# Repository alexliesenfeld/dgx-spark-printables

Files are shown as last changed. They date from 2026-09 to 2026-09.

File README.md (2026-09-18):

# 3D-printable mounts for NVIDIA DGX Spark and other GB10 systems

3D-printable mounts for the **original NVIDIA DGX Spark** and other
**NVIDIA GB10 systems**: **ASUS Ascent GX10**, **GIGABYTE AI TOP ATOM**,
**MSI EdgeXpert AI**, **Lenovo ThinkStation PGX**, and **Acer Veriton GN100**.

The repository includes editable `.scad` sources, `.stl` exports, `.3mf` print
projects, and rendered previews and 360° turnaround videos of both designs.

## 10-inch rack mount

[`spark-rack-10/`](spark-rack-10/) holds the computer behind a **254 × 88 mm
front panel**, sized for a **10-inch, 2U rack position**. The front panel has
mounting holes for **two 80 mm fans**. An open top and a base with ventilation
channels leave the device accessible, while rear stops locate it in the holder.

The design prioritizes airflow and a stable fit when connecting or removing
cables. The large fan openings are free of printed grilles to minimize airflow
restriction and avoid adding grille-related noise or vibration.

**Printed rack mount**

| Installed in the rack | Front view | Fans and support detail |
| --- | --- | --- |
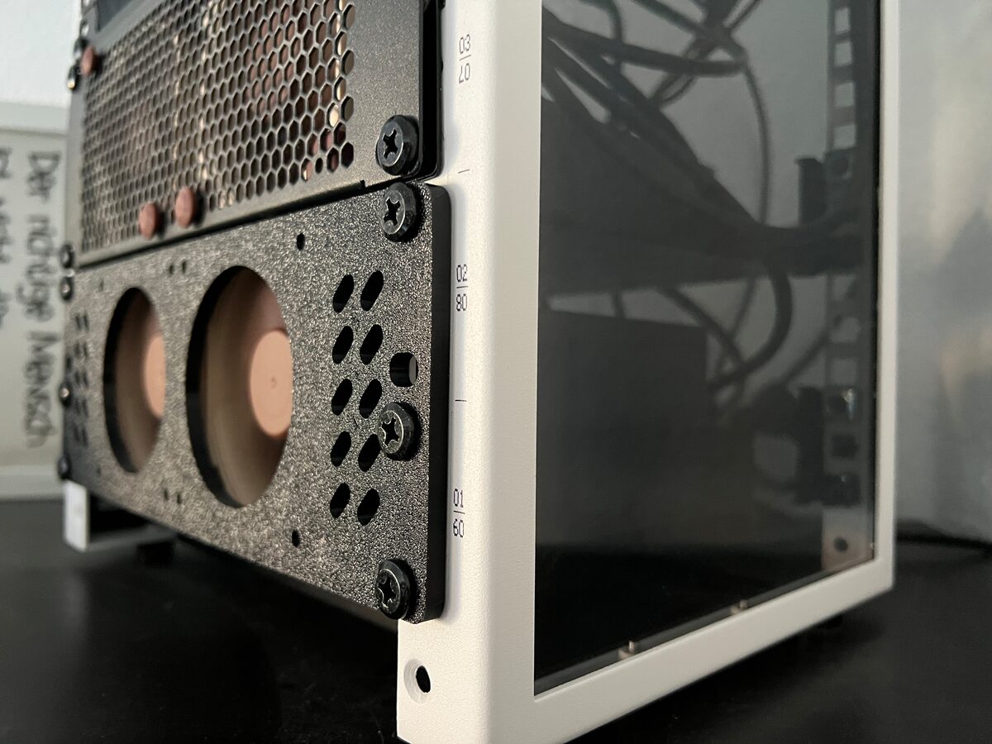
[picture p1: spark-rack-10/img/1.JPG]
Printed DGX Spark mount installed in a 10-inch rack
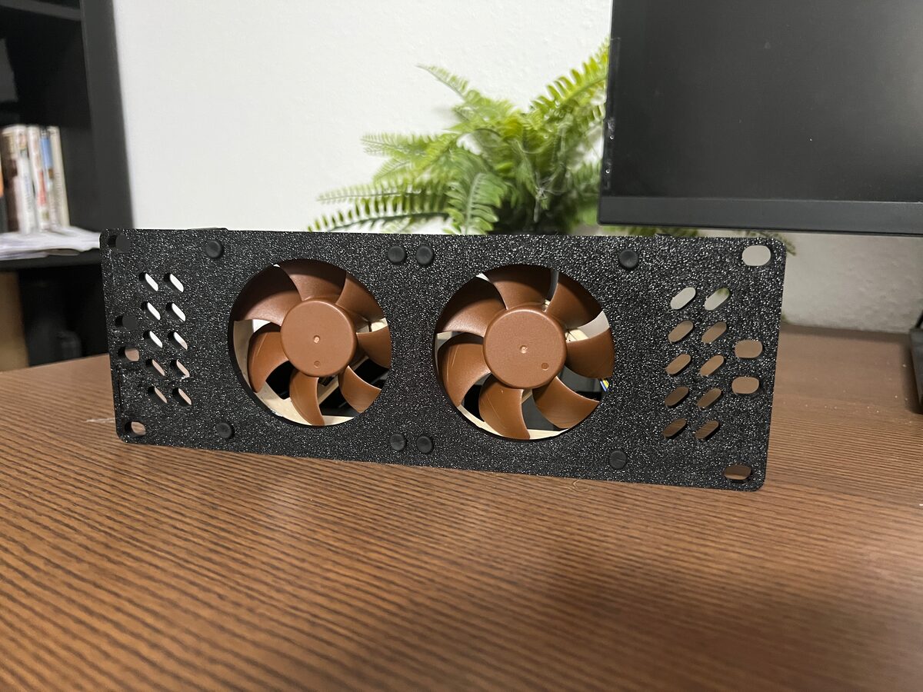
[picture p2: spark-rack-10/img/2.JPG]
Front view of the printed rack mount with two fans
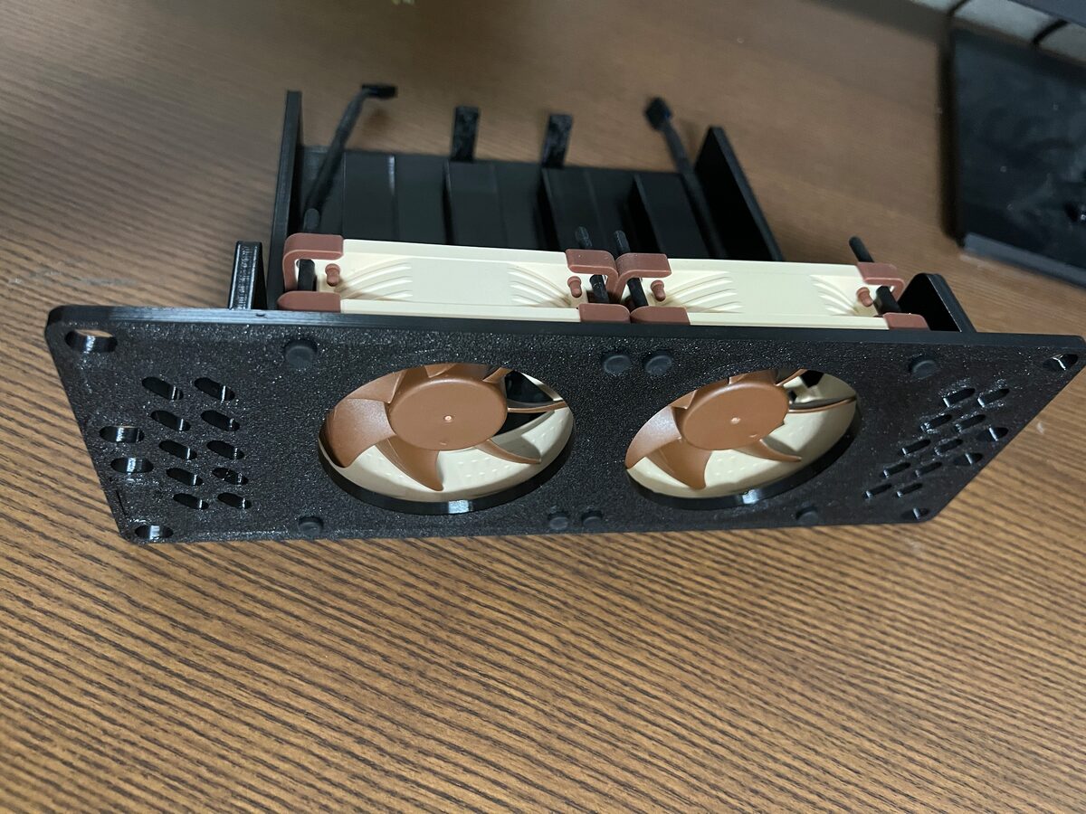
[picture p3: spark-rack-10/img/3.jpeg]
Top view showing the fans and open device supports
|  |  |  |

| Device installed | Running in the rack | Rear connector access |
| --- | --- | --- |
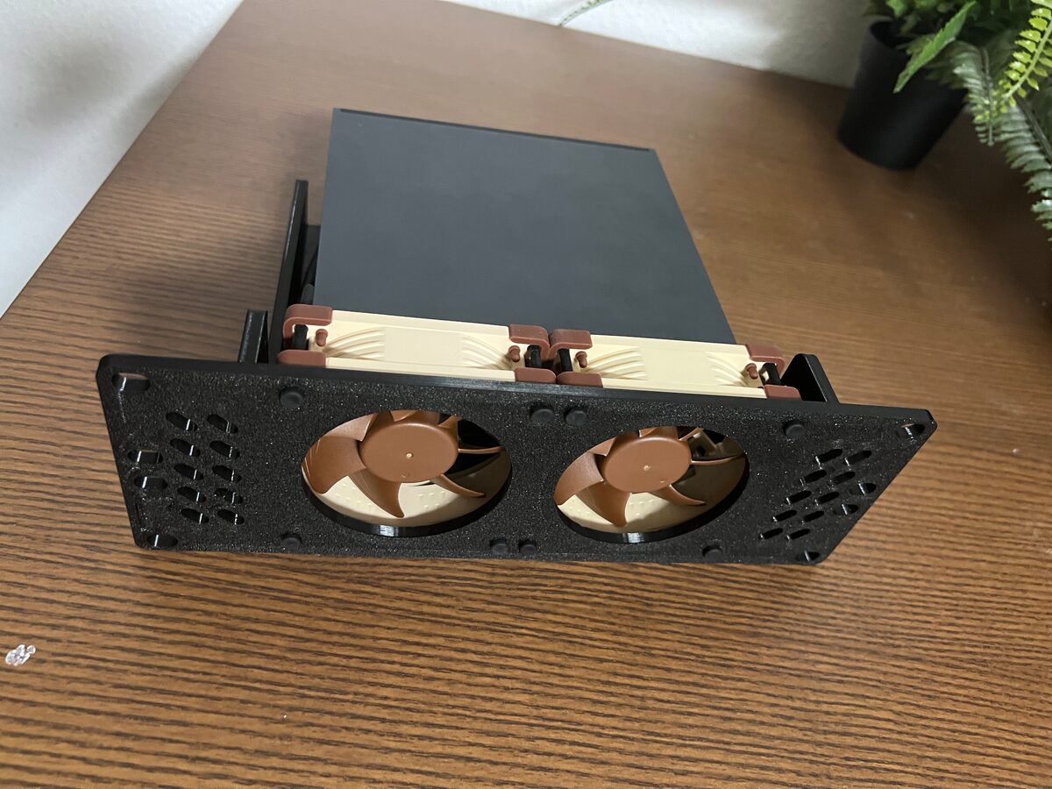
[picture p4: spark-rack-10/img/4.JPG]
GB10 system seated in the printed rack mount
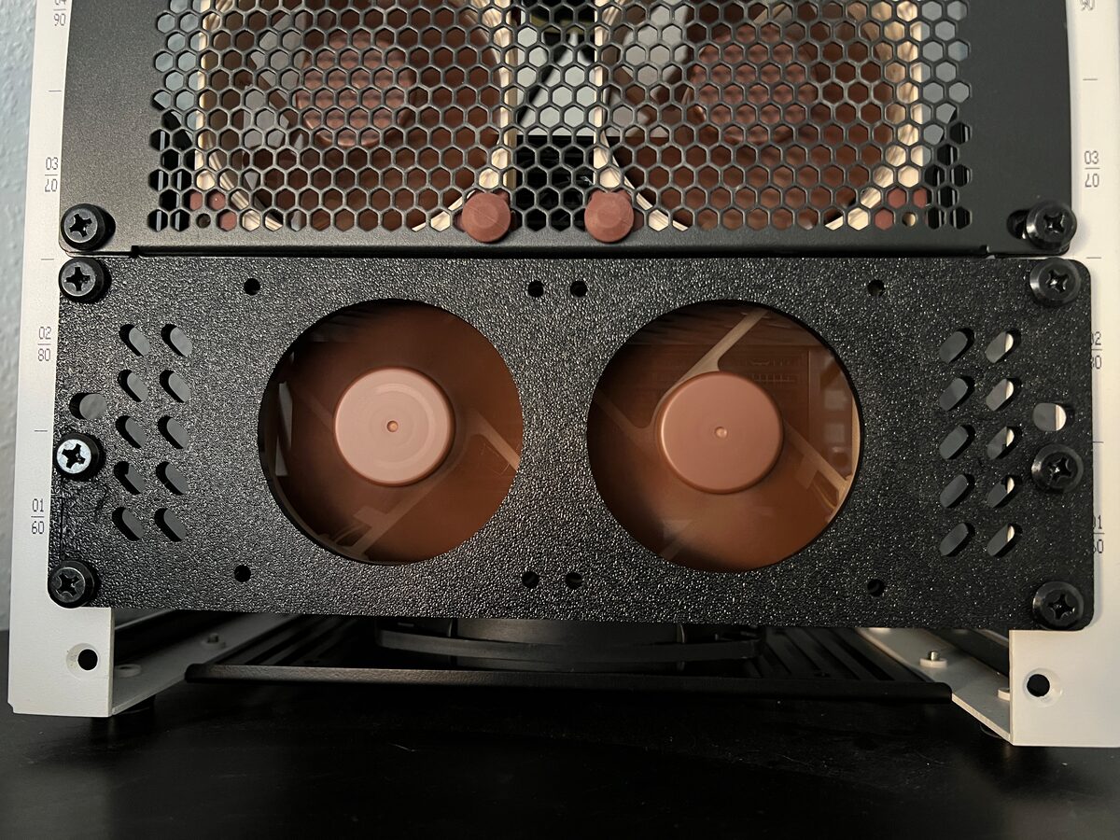
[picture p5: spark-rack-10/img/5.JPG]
Front view of the rack-mounted system with fans running
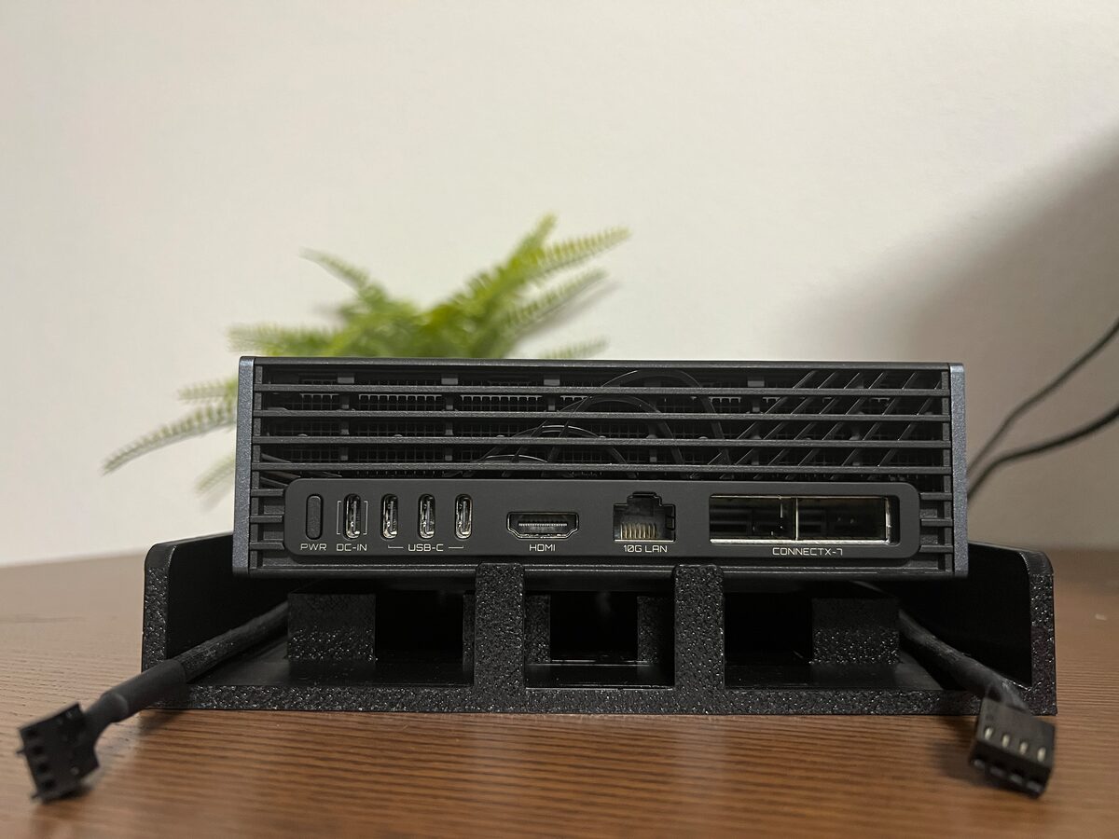
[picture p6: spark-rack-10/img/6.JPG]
Rear view showing accessible connectors and device support
|  |  |  |

**Turnaround previews**

| Horizontal turnaround preview | Vertical turnaround preview |
| --- | --- |
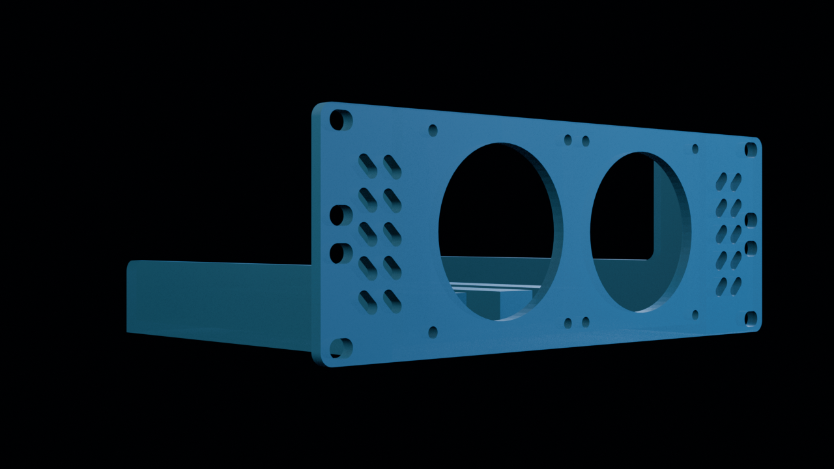
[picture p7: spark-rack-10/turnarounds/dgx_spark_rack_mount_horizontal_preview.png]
10-inch DGX Spark rack mount, horizontal turnaround preview
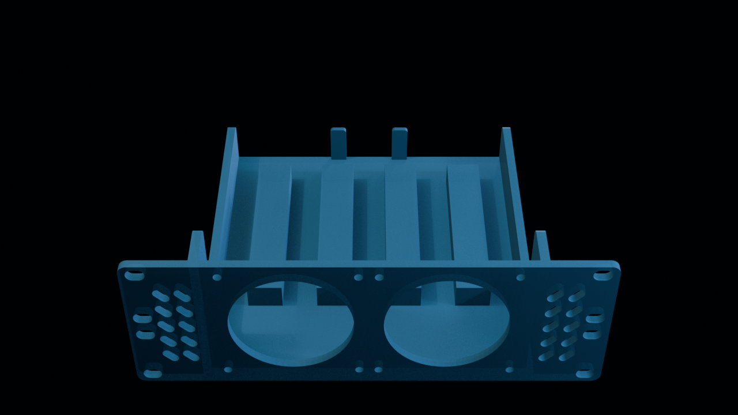
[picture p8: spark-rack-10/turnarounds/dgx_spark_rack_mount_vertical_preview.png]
10-inch DGX Spark rack mount, vertical turnaround preview
|  |  |

**Horizontal turnaround**

https://github.com/user-attachments/assets/c2208833-c9f4-418d-8570-8aad48857cc8

**Vertical turnaround**

https://github.com/user-attachments/assets/7938ebce-b39c-4762-b75c-36b6145284a8

[OpenSCAD source](spark-rack-10/dgx_spark_rack_mount.scad) ·
[STL model](spark-rack-10/dgx_spark_rack_mount.stl) ·
[3MF project](spark-rack-10/dgx_spark_rack_mount.3mf) ·
[Demo assembly](spark-rack-10/dgx_spark_rack_mount_demo.scad) ·
[Load-test notes](spark-rack-10/load_test/README.md)

### Cooling observations

In my own rack-mount comparison tests, CPU and GPU temperatures were on average
about **5 °C lower** with the open design, with differences of up to **8 °C** at
individual temperature peaks. These results describe my test setup; actual
temperatures depend on the device, workload, room temperature, and rack airflow.
See the [load-test notes and plots](spark-rack-10/load_test/) for context.

| CPU / ACPI temperatures | GPU temperatures |
| --- | --- |
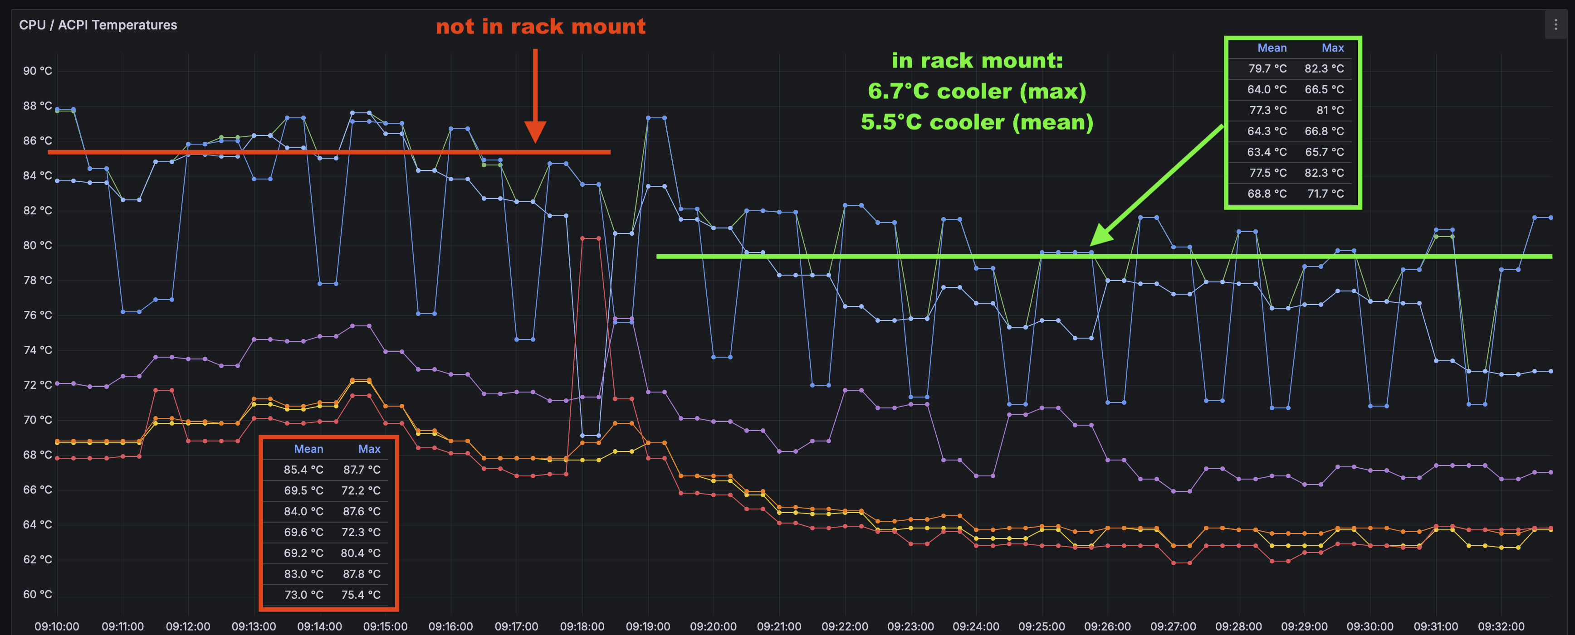
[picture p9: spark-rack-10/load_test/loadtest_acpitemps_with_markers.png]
Annotated CPU and ACPI temperature plot before and after installation in the rack mount
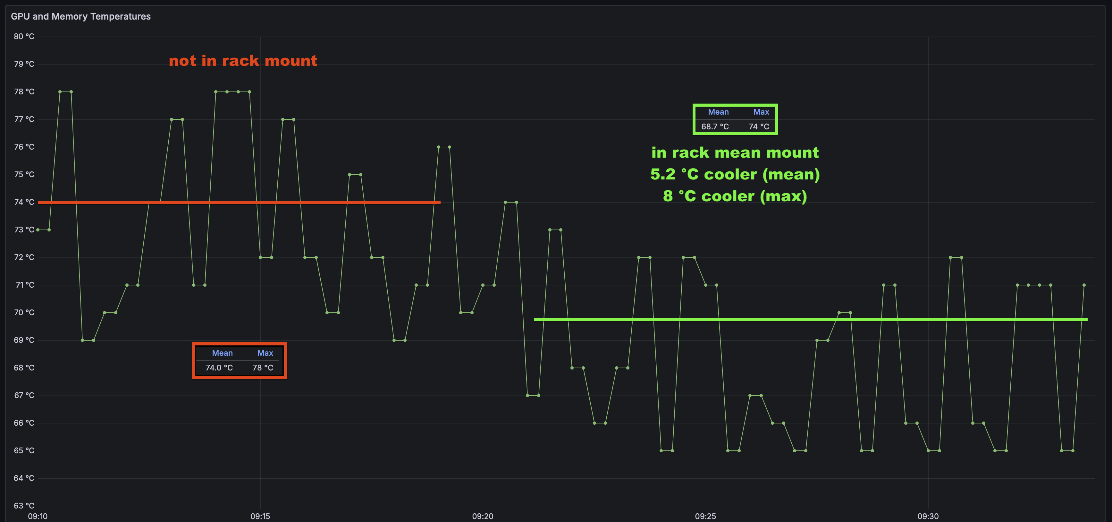
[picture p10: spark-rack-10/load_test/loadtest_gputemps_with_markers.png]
Annotated GPU temperature plot before and after installation in the rack mount
|  |  |

Click either plot to view the annotations at full resolution.

## Under-desk mount

[`spark-atom/`](spark-atom/) frees up desk space by securing the computer beneath
a desk or table, with support for the device during everyday use and cable
changes. It consists of **three printable parts**: two side mounts and a separate
ventilated bottom plate. Four screws secure the upper flanges to the tabletop;
the side mounts support the plate and retain the device with front stops and
flexible rear tabs.

The bottom plate supports the device from below and helps set the spacing
between the side mounts during assembly. Together, the plate and side supports
spread the load and limit unwanted movement. The plate cutouts and side openings
leave room for airflow; check their alignment with your device's vents when
adapting the model.

Use screws suitable for the tabletop material and thickness. Print strength
depends on the filament, orientation, wall count, infill, and layer adhesion;
the [model guide](spark-atom/README.md) includes dimensions, print settings, and
installation details.

**Under-desk mount examples**

| Rear connector access | Bottom plate | Rear support detail | Side ventilation |
| --- | --- | --- | --- |
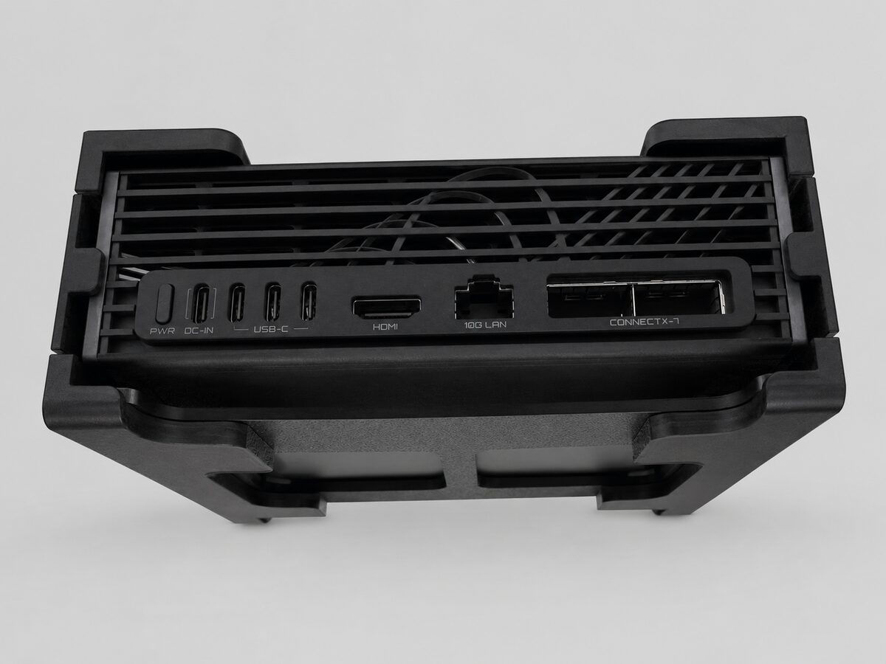
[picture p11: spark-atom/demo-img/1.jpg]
Rear connectors accessible with the GB10 system in the under-desk mount
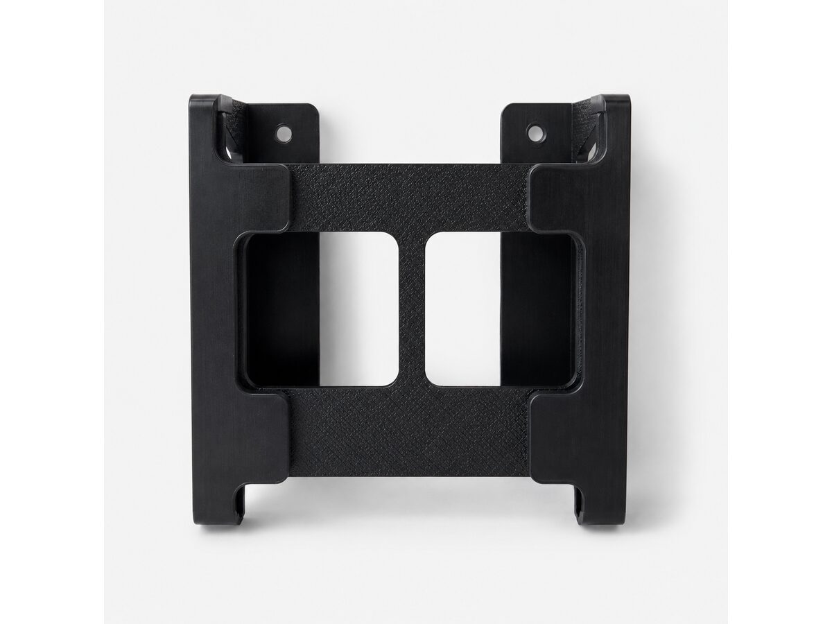
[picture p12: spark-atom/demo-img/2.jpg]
Underside of the mount showing the ventilated bottom plate
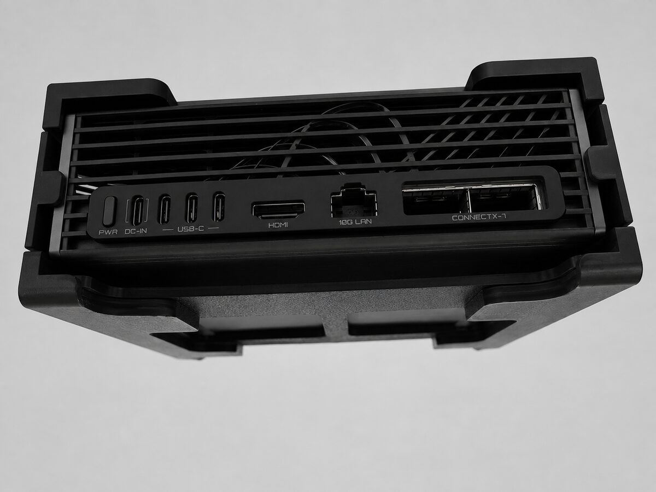
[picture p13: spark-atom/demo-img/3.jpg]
Rear view of the device seated between the side mounts
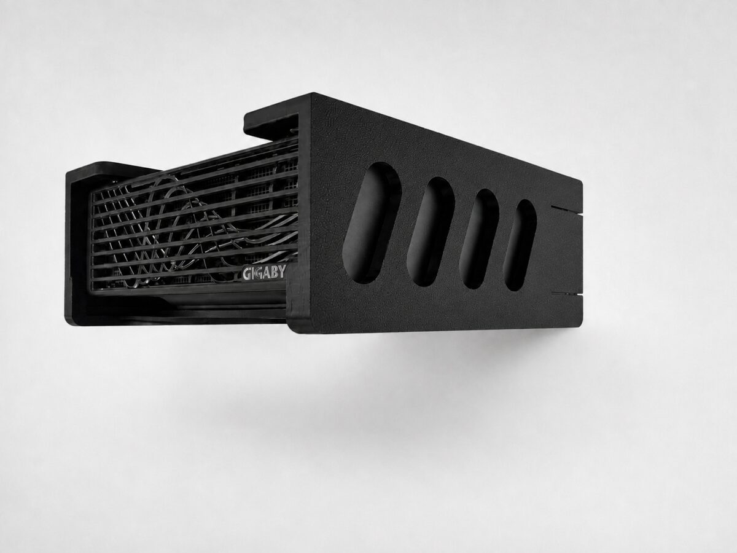
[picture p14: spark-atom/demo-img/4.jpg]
Side view of the mounted device and ventilation openings
|  |  |  |  |

**Turnaround previews**

| Horizontal turnaround preview | Vertical turnaround preview |
| --- | --- |
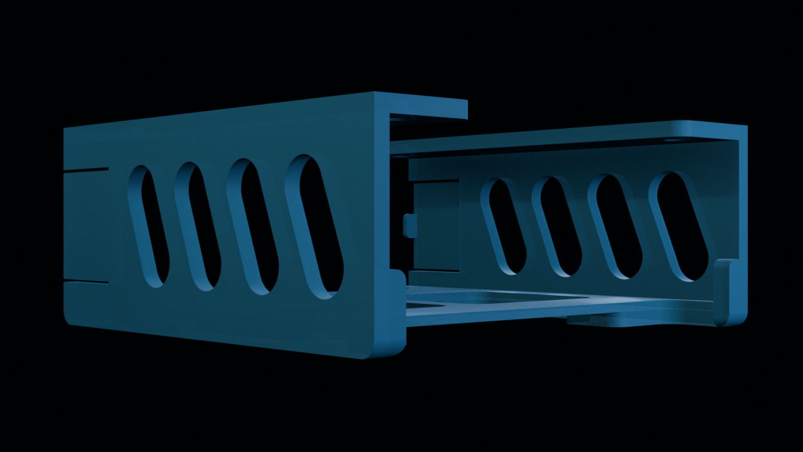
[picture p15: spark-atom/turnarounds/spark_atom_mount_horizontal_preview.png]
DGX Spark and AI TOP ATOM under-table mount, horizontal turnaround preview
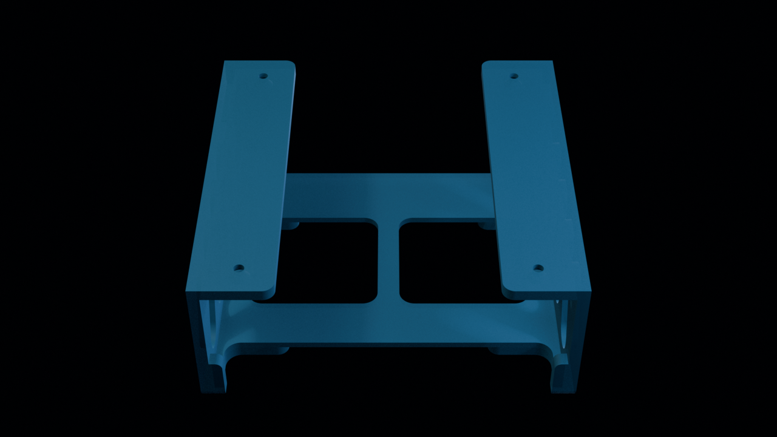
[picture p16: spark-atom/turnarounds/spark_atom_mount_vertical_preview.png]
DGX Spark and AI TOP ATOM under-table mount, vertical turnaround preview
|  |  |

**Horizontal turnaround**

https://github.com/user-attachments/assets/820ae4a6-639c-43a1-a501-b3cc796e51cc

**Vertical turnaround**

https://github.com/user-attachments/assets/ac608dab-5ee2-4ecf-ad42-badc45d0a388

[Detailed dimensions and installation](spark-atom/README.md) ·
[OpenSCAD source](spark-atom/spark_atom_mount.scad) ·
[STL assembly](spark-atom/spark_atom_mount.stl) ·
[Print layout](spark-atom/spark_atom_print.scad) ·
[Print-layout STL](spark-atom/spark_atom_print.stl) ·
[Bottom-plate 3MF](spark-atom/spark_atom_print_plate.3mf) ·
[Side-mount 3MF](spark-atom/spark_atom_print_sides.3mf)

## Support

If you find these models useful, consider supporting the project.

Your support helps improve the current models and develop more 3D-printable
mounts, gadgets, and utilities for NVIDIA DGX Spark and other GB10 systems
in the future.

<a href="https://buymeacoffee.com/alexliesenfeld">Buy Me a Coffee</a>
<a href="https://github.com/sponsors/alexliesenfeld">GitHub Sponsors</a>

## Device fit and vendor variants

Both models currently use a **150 × 150 × 50.5 mm** device envelope. They are
intended for DGX Spark and similarly sized vendor variants; fit depends on the
actual enclosure, feet, vents, and connector positions. Measure your device and
adjust `device_width`, `device_depth`, `device_height`, and the clearance
parameters in the OpenSCAD source before printing if needed.

The under-table demo also includes underside references for NVIDIA, GIGABYTE,
ASUS GX10, MSI, Acer, and Lenovo systems. These help inspect vent placement;
they do not establish that every variant fits the default dimensions.

## Printing

**PETG is recommended** for its heat resistance and strength. PLA can also be
used, but it has lower heat resistance than PETG and may soften or deform if
the mount gets too warm, especially during sustained heavy use of the system.
Inspect the finished print for cracks, poor layer adhesion, and other defects
before mounting the device.

1. Open the relevant `.scad` file in OpenSCAD and check the dimensions for your
   device and installation.
2. Select the printable parts, render them, and export STL files. For the
   under-table mount, use `spark_atom_print.scad` for the arranged print layout
   or export the left side, right side, and bottom plate separately.
3. Slice the STL files or start from the supplied 3MF projects. Regenerate the
   STL exports after changing the source dimensions. Demo assemblies include
   visualization geometry and are for previewing the installation.

The original MP4 videos, PNG previews, Blender scenes, and rendering scripts are
in each model's `turnarounds/` directory. Click a preview image to open its MP4.

## License

The models and design source files are licensed under
[Creative Commons Attribution-NonCommercial 4.0 International (CC BY-NC 4.0)](LICENSE).
You may download, print, modify, and share them for noncommercial purposes.
When sharing files or adaptations, credit Alexander Liesenfeld, retain the
license notice, and indicate any changes.

Commercial sales of the digital files or printed models, including modified
versions, require prior written permission from
[Alexander Liesenfeld](https://github.com/alexliesenfeld).

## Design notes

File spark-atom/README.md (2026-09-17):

# GIGABYTE AI TOP ATOM under-table mount

This is a parametric OpenSCAD project for mounting a GIGABYTE AI TOP ATOM
(DGX Spark-class system) beneath a table.

Device envelope: **150 mm wide × 150 mm deep × 50.5 mm high**.

The mount now consists of **three independent printable components**: a left
side mount, a right side mount, and a loose ventilated bottom plate. Nothing in
the plate bridges or joins the two side mounts.

The loose plate is exactly **151 × 150 × 3 mm**: the 150 mm device width plus
1 mm total wiggle room, centered as 0.5 mm per side. In the assembled view it
occupies approximately X=5.01–156.01 mm and Y=0–150 mm inside the **151.02 ×
151 mm** device pocket. Each side mount has a continuous **3.5 mm inward × 5 mm
thick** support lip running from front to rear beneath the plate. Its inward
edge follows the nominal widened front-cutout boundary but deliberately keeps a
square inner docking corner rather than inheriting the plate's 2 mm open-edge
radius. Two
**31 mm inward × 5 mm thick** lower support fields remain over this continuous
layout, extending approximately 30.99 mm beneath each plate edge. Rather than
using generic rounded rectangles, each field is intersected with the exact
bottom-plate outline. The front field follows the plate from Y=12–50 mm around
its 24 mm solid core at Y=19–43 mm. The rear field follows Y=94.5–142.5 mm
around its 34 mm solid core at Y=101.5–135.5 mm. Their curved transitions
therefore coincide exactly with the adjacent plate cutouts when viewed from
below. The two free inward-pointing corners of every wide support field have a
**5 mm radius**; the narrow front/rear docking tabs remain unchanged. A middle
support rib connects the front and rear fields beneath each
plate side rim. It is 11 mm inward along the center cutouts' straight edges and
flares through their exact 7 mm end arcs, keeping the entire underside profile
aligned. Behind the rear field, an 11 mm support tail continues to the physical
back edge with the same square inner docking corner. It does not inherit the
rear plate cutout's 2 mm open-edge radius. All plate-support
geometry joins the side walls before one shared rear-bottom subtraction. The
rear holder, wall, and stopper therefore retain the continuous 5 mm Y/Z curve
approved for that region. This is independent of the square inner docking
corners in the bottom view; those remain unrounded. The front holder end also
remains square in the Y/Z side profile. The continuous support lip keeps
everything connected to the walls.
The device sits on top of the plate at Z=8 mm.
The SCAD assembly retains an imperceptible 0.01 mm display gap so F6 does not
fuse the three touching components into one mesh.

At the rear, each side wall has an **11 mm-wide alignment stop** behind the
plate. Each stop joins its side wall across the tiny CAD separation and extends
from the mount bottom exactly to the plate's top surface, so it retains the
loose plate without projecting into the device space. Its lower profile follows
the same **5 mm front-to-back rear curve** as the wall, filling the rear corner
without leaving a floating tab. Each stop also has a **3 mm radius** on its top
inward corner.

The existing ventilation layout remains on the loose plate. The front opening
extends 2 mm beyond each shortened 5.5 mm front stopper tip, making it 4 mm
wider overall. The rear opening and the two
**59.51 mm-wide** rounded longitudinal openings align with the inward ends of
the lower support pads, leaving approximately 10.99 mm-wide solid side rims
away from the front.
The longitudinal openings retain their 10 mm center bridge. The plate underside
remains flat where it seats on the support pads. The front stoppers project
**5.5 mm inward**, half the support-pad reach.

The front and rear plate openings have **2 mm radii** at their open-edge
corners and retain **7 mm radii** at their inward corners.

The exposed front- and rear-bottom edges of both side mounts use a **5 mm
radius**. The front curve continues through the lower leading edge of each
front stopper tab.

The top screw-mounting flanges are **35 mm wide**, including the 5 mm side wall,
so they extend **30 mm inward over the device**. Each flange has two holes
placed symmetrically **13 mm from the physical front and rear ends**. Their
centers sit exactly on the exposed flange centerline and align with the front
and rear bottom-plate openings. This provides a straight approximately **6
mm-diameter screwdriver-shaft path from below** while retaining 10.5 mm of
material on both sides of each 9 mm screw-head recess. The two free inward
corners of each flange have a **5 mm radius**; the outer wall-attachment edge
remains square.

At the rear of each side wall, two square-ended **30 × 1 mm** horizontal slots
leave a centered approximately **35.33 mm-high flexible tongue** between them. The tongue is reduced
from the 5 mm wall thickness to **2 mm** and is flush with the outer wall
surface. The 3 mm reduction is taken entirely from the device-facing inner face,
with a rounded transition into the full wall at the fixed end.
Each tongue carries one rear stopper, giving two mirrored stoppers in total.
Each stopper projects **3 mm inward from the normal wall face × 2 mm
front-to-back × 10 mm high** and has 2 mm radii on both corners of its free
inward edge. Both front contact faces remain at Y=151 mm. The stoppers and the
entire rear of the side mounts end together at Y=153 mm, leaving no frame behind
them.

Each side wall has four **39 × 16 mm** capsule-shaped ventilation holes,
giving eight openings in total. They lean **68°** toward the rear and form one
evenly spaced row between the physical front edge and the rear Sprungfeder
root. Their approximately **24.62 mm** horizontal projections preserve the
previous first and
last openings' **11.625 mm** distances from the front and rear boundaries. The
three internal gaps are evenly reduced to approximately **2.43 mm**. Every
opening is centered vertically at Z=32.76 mm, midway across the complete
visible side-wall height, including the wall beside the 5 mm top mount. This
remains independent of the device and loose plate positions. Its approximately
37.33 mm vertical projection leaves approximately **14.09 mm** of wall above
and below.

## Files

- `spark_atom_mount.scad` — adjustable source, part exports, and assembly view
- `spark_atom_mount.stl` — generated export; regenerate it after SCAD changes
- `spark_atom_demo.scad` — separate OpenSCAD demo with the device installed
- `spark_atom_print.scad` — both side mounts laid wall-face-down beside the
  loose plate in a separated print layout
- `images/asus-gx10-bottom.jpg` — supplied underside reference photograph
- `images/asus-gx10-bottom-projection.scad` — compressed 160 × 160, 16-shade
  demo projection derived from the photograph
- `images/NVIDIA-DGX-SPARK-Bottom.jpg` — supplied DGX Spark underside reference
- `images/nvidia-dgx-spark-bottom-projection.scad` — compressed 160 × 160,
  16-shade demo projection derived from the DGX Spark photograph
- `images/gigabyte-top-ai-nano.jpg` — supplied Gigabyte underside reference
- `images/gigabyte-top-ai-nano-projection.scad` — compressed 160 × 160,
  16-shade demo projection derived from the Gigabyte photograph
- `images/msi.png` — supplied MSI underside reference
- `images/msi-bottom-projection.scad` — compressed 160 × 160, 16-shade MSI
  demo projection
- `images/acer.jpg` — supplied Acer underside reference
- `images/acer-bottom-projection.scad` — compressed 160 × 160, 16-shade Acer
  demo projection
- `images/lenovo.png` — supplied Lenovo underside reference
- `images/lenovo-bottom-projection.scad` — compressed 160 × 160, 16-shade
  Lenovo demo projection
- `images/generate_bottom_projection.py` — reusable projection generator

## Generate the parts

Open `spark_atom_mount.scad` in OpenSCAD and change `part` near the top to export:

Use `assembly` (the default) to inspect all three components in their installed
positions. Export `left_side`, `right_side`, and `bottom_plate` separately for
printing. The legacy `tray`, `left_rail`, and `right_rail` selector names remain
as aliases for compatibility; `tray` now shows the three-piece assembly.

Open `spark_atom_print.scad` to render both complete side mounts and the loose
bottom plate. Both mounts are placed on their broad outside wall faces and
packed around the flat plate for a **226.51 × 234.51 mm** footprint, fitting a
250 × 250 mm build plate. Use `bottom_plate_print` directly when only the
isolated plate is needed.

Open `spark_atom_demo.scad` and set `part_override` to `"demo-gx10"`,
`"demo-nvidia"`, `"demo-gigabyte"`, `"demo-msi"`, `"demo-acer"`, or
`"demo-lenovo"` to select the displayed device
underside. The demo renders an
opaque dark 150 × 150 × 50.5 mm device mockup inside the mount with a shallow
grayscale projection derived from the selected photograph. The projections are
visible pixel tiles rather than height maps, and each photograph's bottom edge
is aligned with the device front. The printable `tray` selection contains
neither projection nor the device mockup. A red, centered 135 × 5 mm ventilation
marker remains visible beneath the projection, beginning 15 mm behind the
device's front edge. The mockup's front face visually overlaps the front stopper
plane by 0.2 mm, leaving 1.2 mm behind the device. Do not export a demo for
printing.

Render each printable selection with F6, then export it as STL.

If using the command-line version of OpenSCAD:

```sh
openscad -D 'part="bottom_plate"' -o spark_atom_bottom_plate.stl spark_atom_mount.scad
openscad -D 'part="left_side"' -o spark_atom_left_side.stl spark_atom_mount.scad
openscad -D 'part="right_side"' -o spark_atom_right_side.stl spark_atom_mount.scad
```

## Hardware and installation

- 4 × 4 mm or #8 countersunk/pan-head wood screws, with a length suitable for
  the tabletop
- Optional 0.5–1 mm felt or rubber tape on the rail contact surfaces

Print in PETG, ASA, or another heat-tolerant material with at least four walls
and 30% infill. Print the bottom plate flat. Orient each side mount appropriately
in the slicer and use support only where your printer requires it. The assembled
envelope is approximately **161.02 × 159 × 65.5 mm**. Fasten the side mounts
through their four
flange holes, lay the loose plate on the lower support pads, and slide the device into
the retained pocket.

The distance between the front and rear stops is **151 mm**, providing 0.5 mm
clearance at both ends of the 150 mm-deep enclosure. Internal width is
**151.02 mm**, providing approximately 0.51 mm clearance on each side. The
151 mm plate itself provides exactly 0.5 mm per side around the device.

The loose bottom plate is **3 mm thick**. The side walls, top mounting flanges,
and support ledges are **5 mm thick**. Each front retaining wall
has a **5.5 mm inward width × 6 mm depth** footprint and is **22 mm high** before
the shared bottom curve. Its effective height at the rounded leading edge is
**17 mm**. It is attached to the side wall and begins at the mount's absolute
bottom. Its upper
and lower inward corners retain a **3 mm radius**, giving the tab a gradual,
printable transition from the side wall. Both outer corners remain square.

The inward flange undersides are **60.5 mm** above the side mounts' bottom. With
the plate top at Z=8 mm and the 50.5 mm device above it, this leaves **2 mm of
vertical clearance**. The complete assembled model is **65.5 mm high**.

Do not overtighten the rails against the computer. Check the real enclosure with
calipers before drilling; adjust `device_*` or `clearance` at the top of the SCAD
file if necessary. Confirm that no screw can penetrate the top surface of the
table and periodically inspect the printed parts for heat deformation or cracks.

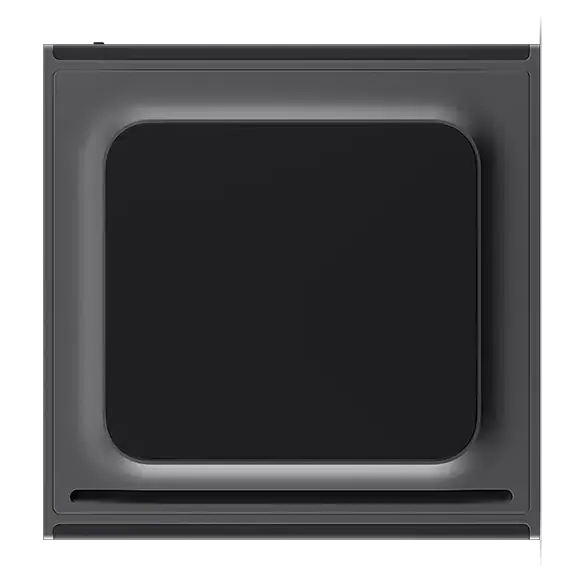
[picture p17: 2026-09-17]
spark-atom/images/lenovo.png

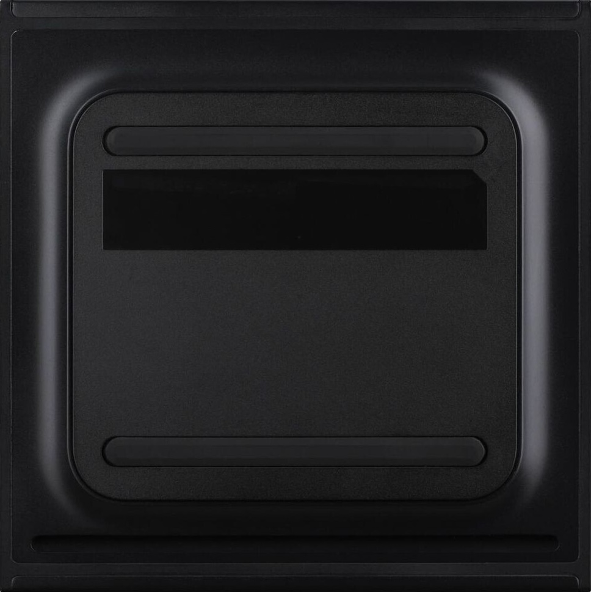
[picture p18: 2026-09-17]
spark-atom/images/acer.jpg

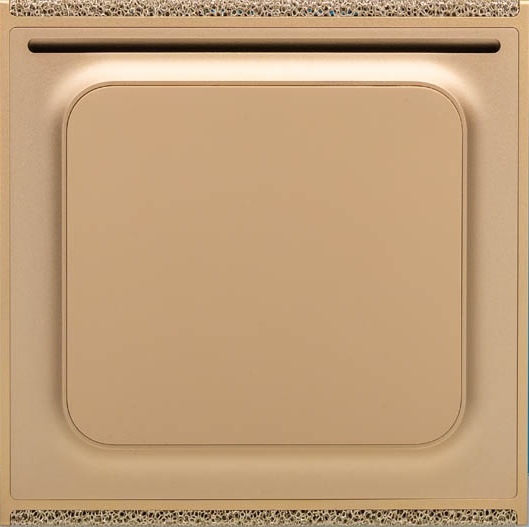
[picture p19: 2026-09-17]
spark-atom/images/NVIDIA-DGX-SPARK-Bottom.jpg

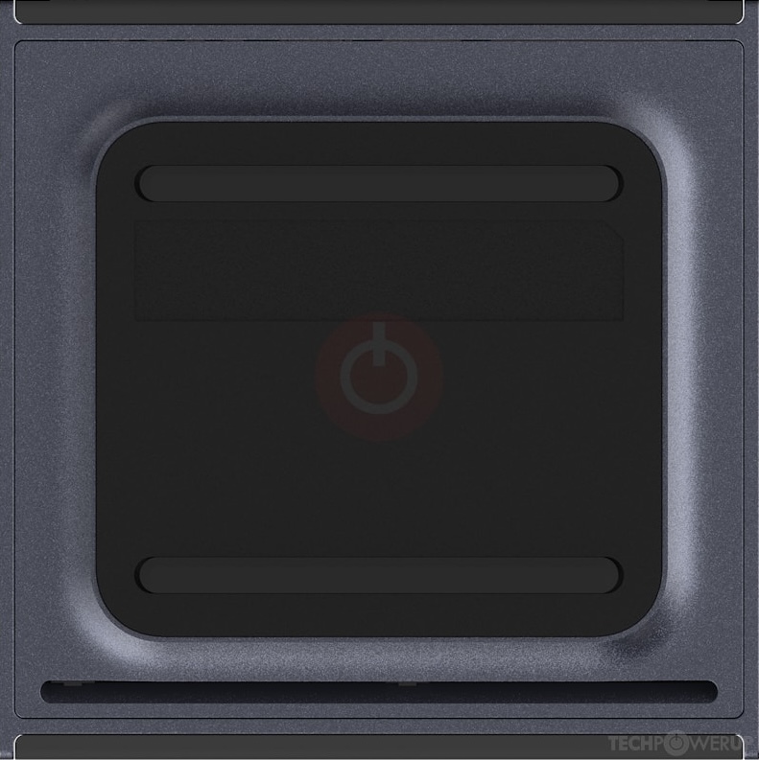
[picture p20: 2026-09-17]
spark-atom/images/gigabyte-top-ai-nano.jpg

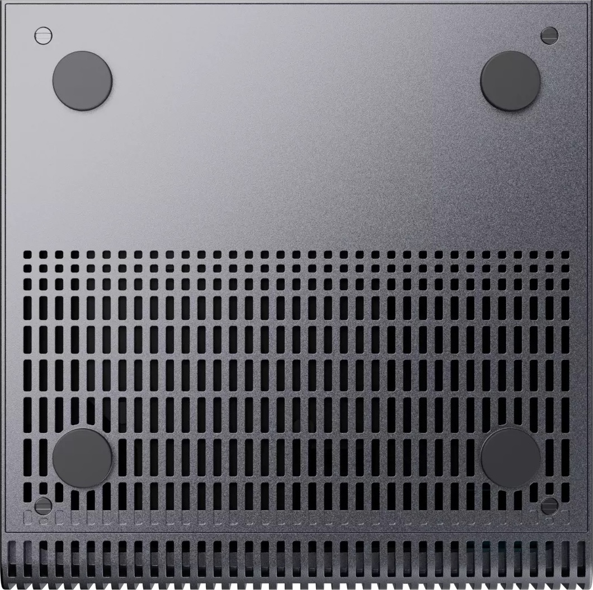
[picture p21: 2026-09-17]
spark-atom/images/asus-gx10-bottom.jpg

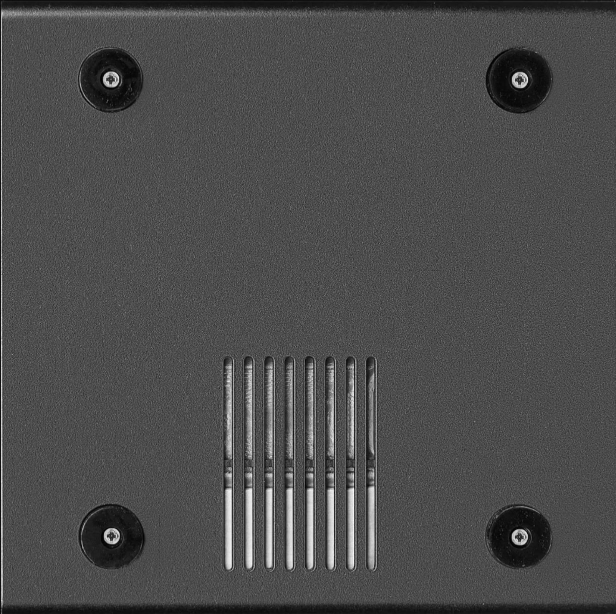
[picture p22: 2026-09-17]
spark-atom/images/msi.png

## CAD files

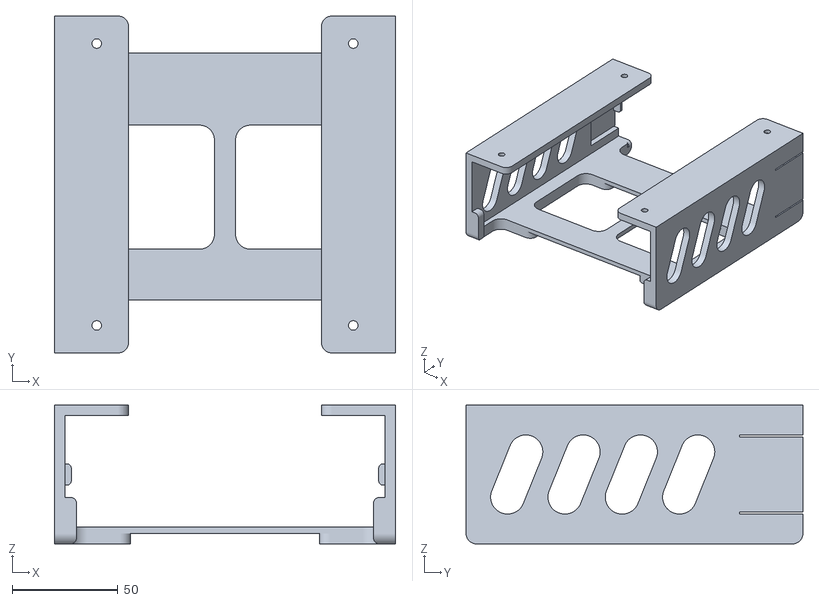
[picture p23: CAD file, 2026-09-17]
spark-atom/spark_atom_mount.stl
161.0 x 159.0 x 65.5

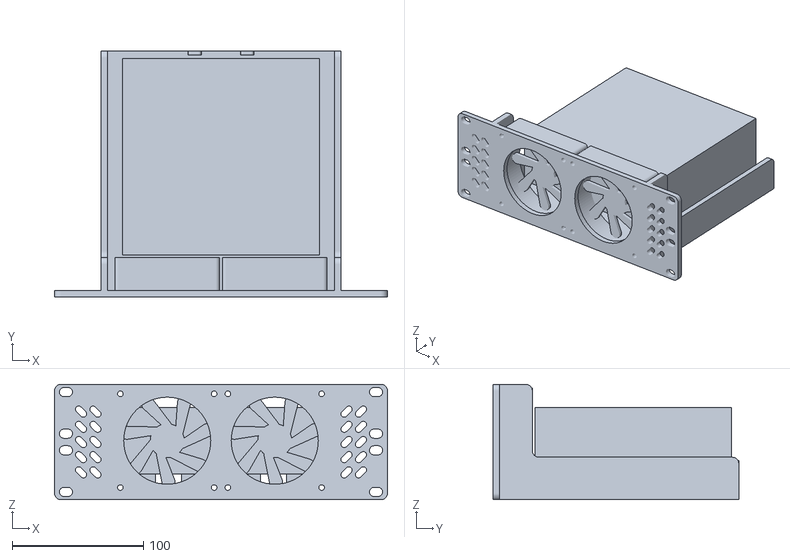
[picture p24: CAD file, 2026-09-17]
spark-rack-10/dgx_spark_rack_mount_demo.stl
254.0 x 187.4 x 88.0

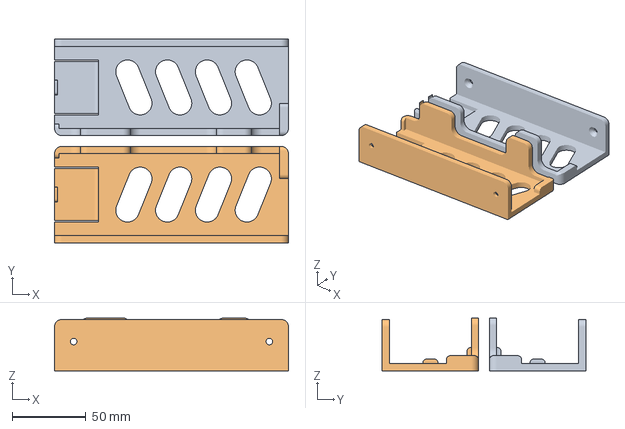
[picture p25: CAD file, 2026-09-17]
spark-atom/spark_atom_print_sides.3mf
159.0 x 138.3 x 36.0 mm
spark_atom_print.stl_1
spark_atom_print.stl_3

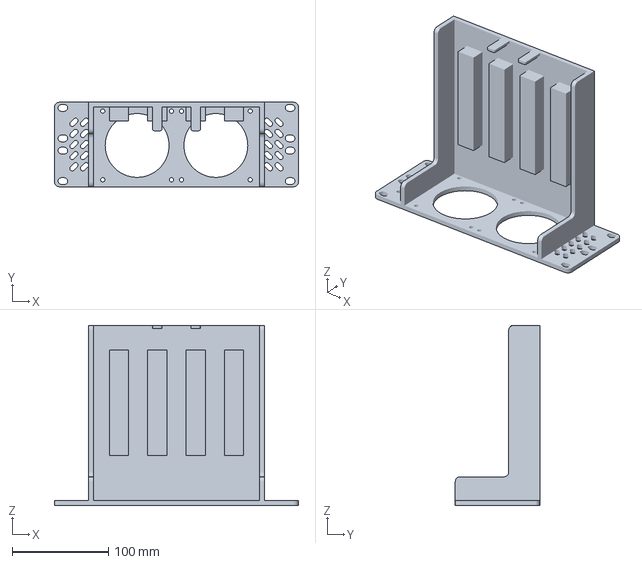
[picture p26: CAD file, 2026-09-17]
spark-rack-10/dgx_spark_rack_mount.3mf
254.0 x 88.0 x 187.4 mm

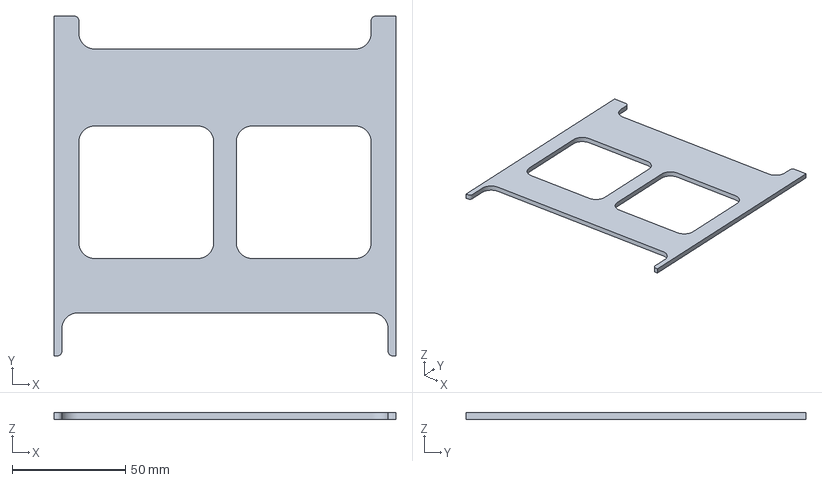
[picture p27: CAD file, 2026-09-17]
spark-atom/spark_atom_print_plate.3mf
151.0 x 150.0 x 3.00 mm

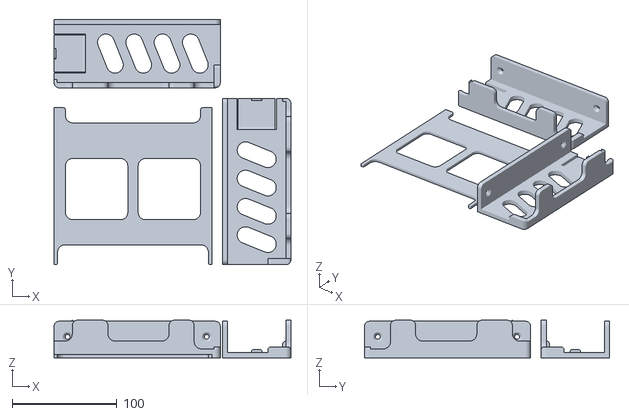
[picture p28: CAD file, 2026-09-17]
spark-atom/spark_atom_print.stl
226.5 x 234.5 x 36.0

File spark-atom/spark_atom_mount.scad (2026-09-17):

/*
 * Under-table mount for the GIGABYTE AI TOP ATOM.
 *
 * Coordinate system in the assembled preview:
 *   X = device width, Y = device depth (front to rear), Z = height.
 *
 * Select a printable part with `part`. The assembled view contains three
 * disconnected printable components: two side mounts and one loose plate.
 */

include <images/asus-gx10-bottom-projection.scad>
include <images/nvidia-dgx-spark-bottom-projection.scad>
include <images/gigabyte-top-ai-nano-projection.scad>
include <images/msi-bottom-projection.scad>
include <images/acer-bottom-projection.scad>
include <images/lenovo-bottom-projection.scad>

part = "assembly"; // [assembly,print_layout,bottom_plate,bottom_plate_print,left_side,right_side,demo-gx10,demo-nvidia,demo-gigabyte,demo-msi,demo-acer,demo-lenovo,demo,tray,left_rail,right_rail]
selected_part = is_undef(part_override) ? part : part_override;

device_width = 150;
device_depth = 150;
device_height = 50.5;
device_vent_width = 135;
device_vent_depth = 5;
device_vent_front_offset = 15;
device_vent_marker_thickness = 0.25;
device_demo_stop_overlap = 0.2;
device_bottom_projection_thickness = 0.05;

width_clearance = 0.5;  // Per side on plate: 151 mm total plate width
depth_clearance = 0.5;  // Front/rear: 151 mm total internal depth
height_clearance = 2;  // Vertical clearance below inward top mounts
wall = 5;
shelf_width = 11;
shelf_thickness = 5;
bottom_support_width = shelf_width + 20;
bottom_support_inner_corner_radius = 5;
top_mount_width = 35;
top_mount_thickness = 5;
rail_flange = top_mount_width - wall;  // Inward extension beyond side wall
top_mount_corner_radius = 5;
rear_side_stop_width = 3;
rear_side_stop_depth = 2;
rear_side_stop_height = 10;
rear_side_stop_corner_radius = 2;
rear_side_stop_embed = 0.2;
rear_plate_stop_corner_radius = 3;
rear_wall_spring_slot_length = 30;
rear_wall_spring_slot_height = 1;
rear_wall_spring_thickness = 2;
rear_wall_spring_relief_depth = wall - rear_wall_spring_thickness;
side_wall_vent_count = 4;
side_wall_vent_length = 39;
side_wall_vent_width = 16;
side_wall_vent_angle = 68;
side_wall_vent_end_margin = 11.625;

floor_thickness = 3;  // Loose plate only; structural holders remain 5 mm
vent_back_offset = 25;  // Front opening depth from the physical front edge
rear_vent_depth = 17.5; // Rear opening extends 17.5 mm into the interior
vent_rear_corner_radius = 7;
vent_open_corner_radius = 2;
front_cutout_side_extension = 2;
// CENTER BOTTOM-PLATE CUTOUTS
// These are the two large openings beneath the device. Length is measured
// front-to-back (Y in this SCAD).
center_plate_bridge_width = 10;
center_plate_cutout_radius = 7;
middle_bottom_support_width =
    shelf_width + center_plate_cutout_radius;
center_plate_front_bridge_depth = 24;
center_plate_rear_bridge_depth = 34;
front_stop_thickness = 6;
front_stop_width = shelf_width / 2;
bottom_support_rail_width =
    front_stop_width - front_cutout_side_extension;
front_stop_corner_radius = 3;
front_bottom_radius = 5;
front_stop_effective_height = 17;
front_stop_height = front_stop_effective_height + front_bottom_radius;

screw_diameter = 4.5;  // Clearance for a 4 mm / #8 wood screw
screw_head_diameter = 9;
screw_head_depth = 2.6;
mount_hole_center_inset = 13;
print_layout_gap = 10;
print_bed_width = 250;
print_bed_depth = 250;
$fn = 48;

rear_side_stop_contact_y = device_depth + 2 * depth_clearance;
rail_length = rear_side_stop_contact_y + rear_side_stop_depth;
rear_side_stop_anchor_y = rail_length;
// Prevent OpenSCAD from fusing touching parts in the assembled STL. This tiny
// display/export gap disappears when the loose plate rests on the real ledges.
assembly_part_gap = 0.01;
bottom_plate_width = device_width + 2 * width_clearance;
device_pocket_width = bottom_plate_width + 2 * assembly_part_gap;
rail_origin_spacing = device_pocket_width + 2 * wall;
bottom_plate_x = wall + assembly_part_gap;
bottom_plate_y = assembly_part_gap;
bottom_plate_z = shelf_thickness + assembly_part_gap;
bottom_plate_depth = device_depth;
device_support_z = bottom_plate_z + floor_thickness;
rear_plate_stop_x = wall;
rear_plate_stop_width = shelf_width;
rear_plate_stop_front_y =
    bottom_plate_y + bottom_plate_depth + assembly_part_gap;
rear_plate_stop_depth = rail_length - rear_plate_stop_front_y;
rear_plate_stop_bottom_z = 0;
rear_plate_stop_height = device_support_z - rear_plate_stop_bottom_z;
center_plate_cutout_front_y = -front_stop_thickness + vent_back_offset +
                               center_plate_front_bridge_depth;
center_plate_cutout_rear_y = rail_length - rear_vent_depth -
                              center_plate_rear_bridge_depth;
center_plate_cutout_length = center_plate_cutout_rear_y -
                             center_plate_cutout_front_y;
front_transverse_cutout_inner_y =
    -front_stop_thickness + vent_back_offset;
rear_transverse_cutout_inner_y =
    rail_length - rear_vent_depth;
front_cutout_inner_left_x =
    wall + front_stop_width - front_cutout_side_extension;
front_cutout_inner_right_x =
    rail_origin_spacing - wall - front_stop_width +
    front_cutout_side_extension;
front_cutout_width =
    front_cutout_inner_right_x - front_cutout_inner_left_x;
front_cutout_depth =
    front_transverse_cutout_inner_y - bottom_plate_y;
front_bottom_support_core_length =
    center_plate_cutout_front_y - front_transverse_cutout_inner_y;
rear_bottom_support_core_length =
    rear_transverse_cutout_inner_y - center_plate_cutout_rear_y;
front_bottom_support_y =
    front_transverse_cutout_inner_y - vent_rear_corner_radius;
front_bottom_support_depth =
    center_plate_cutout_front_y + center_plate_cutout_radius -
    front_bottom_support_y;
rear_bottom_support_y =
    center_plate_cutout_rear_y - center_plate_cutout_radius;
rear_bottom_support_depth =
    rear_transverse_cutout_inner_y + vent_rear_corner_radius -
    rear_bottom_support_y;
rear_bottom_support_tail_y = rear_transverse_cutout_inner_y;
rear_bottom_support_tail_depth =
    bottom_plate_y + bottom_plate_depth -
    rear_bottom_support_tail_y;
center_plate_cutout_width =
    (device_pocket_width - 2 * shelf_width -
     center_plate_bridge_width) / 2;
side_mount_inward_extent =
    max(top_mount_width, wall + bottom_support_width);
// Inward flanges sit above the device and therefore include the loose plate.
inside_height = device_height + height_clearance;
flange_z = device_support_z + inside_height;
device_pocket_depth = device_depth + 2 * depth_clearance;
// Center wall openings and the Sprungfeder in the complete visible side wall,
// including the wall section beside the top mount thickness. This remains
// independent of the installed plate and device position.
side_wall_feature_bottom_z = 0;
side_wall_feature_top_z = flange_z + top_mount_thickness;
side_wall_feature_center_z =
    (side_wall_feature_bottom_z + side_wall_feature_top_z) / 2;
side_wall_vent_projected_height =
    (side_wall_vent_length - side_wall_vent_width) *
    abs(sin(side_wall_vent_angle)) + side_wall_vent_width;
rear_wall_spring_tongue_center_z = side_wall_feature_center_z;
rear_wall_spring_tongue_height = side_wall_vent_projected_height -
                                 2 * rear_wall_spring_slot_height;
rear_wall_spring_tongue_bottom_z = rear_wall_spring_tongue_center_z -
                                    rear_wall_spring_tongue_height / 2;
rear_wall_spring_root_y = rail_length - rear_wall_spring_slot_length;
rear_side_stop_bottom_z = rear_wall_spring_tongue_center_z -
                          rear_side_stop_height / 2;
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

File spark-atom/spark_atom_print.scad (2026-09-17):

/*
 * Print view: both side mounts plus the loose ventilated bottom plate.
 *
 * Both wall assemblies lie on their broad outside faces on the build plate.
 * Together with the loose plate, the compact layout fits a 250 x 250 mm bed.
 */

part_override = "print_layout";
include <spark_atom_mount.scad>

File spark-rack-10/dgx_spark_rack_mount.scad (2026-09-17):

/*
 * 10-inch rack mount with an attached holder for an NVIDIA DGX Spark.
 *
 * Axes in the assembled model:
 *   X = rack width, Y = front-to-rear depth, Z = rack height.
 *
 * Holder dimensions are based on ../spark-atom/spark_atom_mount.scad:
 *   - 150 x 150 x 50.5 mm device
 *   - 10.5 mm device side clearance and 0.5 mm rear clearance
 *   - 173 mm-wide square-channel bottom support beneath the fans/device
 *   - 5 mm structural walls
 *   - open top for unobstructed access and airflow
 *
 * All dimensions are millimetres.
 */

part = "assembly"; // [assembly,front_panel,holder,demo]
selected_part = is_undef(part_override) ? part : part_override;

// De-facto 10-inch rack face width. The horizontal rack slots are centered on
// the common 236.525 mm hole spacing for equal inward/outward tolerance.
front_panel_width = 254;
front_panel_height = 88;
front_panel_thickness = 5;
front_panel_corner_radius = 5;

// M6/FDM-friendly rack slots using the standard 2U outer-hole spacing.
rack_holes_enabled = true;
rack_hole_diameter = 7;
rack_hole_width = 10;
rack_hole_horizontal_spacing_nominal = 236.525;
rack_hole_vertical_spacing = 76.2;
rack_hole_standard_pitch = 15.875;
rack_hole_center_x =
    (front_panel_width - rack_hole_horizontal_spacing_nominal) / 2;
rack_hole_bottom_z =
    (front_panel_height - rack_hole_vertical_spacing) / 2;
rack_hole_top_z = rack_hole_bottom_z + rack_hole_vertical_spacing;
rack_hole_inner_bottom_z =
    rack_hole_bottom_z + 2 * rack_hole_standard_pitch;
rack_hole_inner_top_z =
    rack_hole_top_z - 2 * rack_hole_standard_pitch;
rack_hole_zs = [
    rack_hole_bottom_z,
    rack_hole_inner_bottom_z,
    rack_hole_inner_top_z,
    rack_hole_top_z
];

// DGX Spark envelope and holder clearances copied from the source mount.
device_width = 150;
device_depth = 150;
device_height = 50.5;
width_clearance = 10.5;
depth_clearance = 5.5;
height_clearance = 2;

wall = 5;
floor_thickness = 5;
floor_channel_width = 20;
floor_support_width = 20;
floor_support_front_setback = 20;
floor_support_rear_setback = 20;
back_stopper_thickness = 3;
back_stopper_width = 10;
back_stopper_extra_height = 10;
back_stopper_corner_radius = 2;
wall_top_flat_depth = 20;
wall_profile_corner_radius = 5;
wall_profile_corner_segments = 12;

// Small ventilation slots across the front panel.
vent_slot_angle = 45;
vent_slot_length = 10;
vent_slot_width = 5;
vent_slot_minimum_web = 3;
front_slot_edge_margin_x = 5;
front_slot_edge_margin_z = 5;
front_rack_hole_keepout_web = 2;
front_side_wall_clearance = 0;
front_wall_outward_extension = 1;
front_slot_columns_per_side = 3;
front_slot_outer_columns_removed = 1;

// Two standard 80 mm fans with a 2 mm gap between their frames.
fan_size = 80;
fan_center_spacing = 82;
fan_opening_diameter = 66.4;
fan_mount_hole_spacing = 71.5;
fan_mount_hole_diameter = 4.5;
fan_depth = 25;
fan_device_clearance = 2;

// Fan-demo geometry; these dimensions do not alter the printable mount.
fan_frame_hole_diameter = 4.3;
fan_demo_airflow_diameter = 77;
fan_demo_corner_radius = 3;
fan_demo_hub_diameter = 26;
fan_demo_blade_count = 7;
fan_demo_rotor_thickness = 3;

// The tray overlaps the thin panel slightly so the exported mesh is one solid.
join_overlap = min(0.1, front_panel_thickness / 2);
floor_panel_overlap = 2;

// Preview only; does not affect printable assembly/holder exports.
demo_device_enabled = true;
demo_fans_enabled = true;

$fn = 64;

floor_width = device_width +
              2 * (width_clearance + front_wall_outward_extension);
device_front_offset = fan_depth + fan_device_clearance;
holder_depth = device_front_offset + device_depth + depth_clearance;
floor_depth = device_depth + depth_clearance;
device_support_z = floor_thickness;
// Keep rear-mounted fan frames above the bottom plate and align the installed
// device's vertical center with the fan centers.
fan_center_z = max(front_panel_height / 2,
                   floor_thickness + fan_size / 2);
holder_z = fan_center_z - device_support_z - device_height / 2;
device_support_top_z = holder_z + device_support_z;
floor_support_top_z = device_support_top_z;
back_stopper_top_z =
    floor_support_top_z + back_stopper_extra_height;
floor_support_count = floor(
    (floor_width + floor_channel_width) /
    (floor_support_width + floor_channel_width));
floor_pattern_width =
    floor_support_count * floor_support_width +
    (floor_support_count - 1) * floor_channel_width;
floor_side_channel_width =
    (floor_width - floor_pattern_width) / 2;
vent_slot_projected_x =
    (vent_slot_length - vent_slot_width) *
    abs(cos(vent_slot_angle)) + vent_slot_width;
vent_slot_projected_z =
    (vent_slot_length - vent_slot_width) *
    abs(sin(vent_slot_angle)) + vent_slot_width;
front_slot_count_z = floor(
    (front_panel_height - 2 * front_slot_edge_margin_z +
     vent_slot_minimum_web) /
    (vent_slot_projected_z + vent_slot_minimum_web));
front_slot_pitch_z =
    (front_panel_height - 2 * front_slot_edge_margin_z -
     vent_slot_projected_z) /
    (front_slot_count_z - 1);

// The walls begin at the panel bottom to meet the square-channel base.
wall_base_z = 0;
holder_height = front_panel_height - wall_base_z;
wall_rear_height =
    device_support_top_z + device_height / 4 - wall_base_z;
wall_plateau_start_y =
    wall_top_flat_depth + 2 * wall_profile_corner_radius;

holder_outer_width = floor_width + 2 * wall;
holder_x = (front_panel_width - holder_outer_width) / 2;
floor_x = holder_x + wall;
actual_width_clearance = (floor_width - device_width) / 2;
holder_y = front_panel_thickness - join_overlap;
device_y = holder_y + device_front_offset;
floor_y = device_y;
floor_support_y = floor_y + floor_support_front_setback;
floor_support_depth =
    device_depth - floor_support_front_setback -
    floor_support_rear_setback;
base_floor_y = front_panel_thickness - floor_panel_overlap;
base_floor_depth = floor_y + floor_depth - base_floor_y;
back_stopper_y =
    base_floor_y + base_floor_depth - back_stopper_thickness;
back_stopper_support_indices = [
    floor(floor_support_count / 2) - 1,
    floor(floor_support_count / 2)
];
back_stopper_xs = [for (i = back_stopper_support_indices)
    floor_x + floor_side_channel_width +
    i * (floor_support_width + floor_channel_width) +
    (floor_support_width - back_stopper_width) / 2
];
fan_center_xs = [
    front_panel_width / 2 - fan_center_spacing / 2,
    front_panel_width / 2 + fan_center_spacing / 2
];
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

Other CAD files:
spark-atom/spark_atom_demo.scad
spark-atom/images/acer-bottom-projection.scad
spark-atom/images/asus-gx10-bottom-projection.scad
spark-atom/images/gigabyte-top-ai-nano-projection.scad
spark-atom/images/lenovo-bottom-projection.scad
spark-atom/images/msi-bottom-projection.scad
spark-atom/images/nvidia-dgx-spark-bottom-projection.scad
spark-atom/turnarounds/spark_atom_mount_horizontal.blend
spark-atom/turnarounds/spark_atom_mount_vertical.blend
spark-rack-10/dgx_spark_rack_mount.stl
spark-rack-10/dgx_spark_rack_mount_demo.scad
spark-rack-10/turnarounds/dgx_spark_rack_mount_horizontal.blend
spark-rack-10/turnarounds/dgx_spark_rack_mount_vertical.blend
turnarounds/dgx_spark_rack_mount_horizontal.blend
turnarounds/dgx_spark_rack_mount_vertical.blend
turnarounds/spark_atom_mount_horizontal.blend
turnarounds/spark_atom_mount_vertical.blend

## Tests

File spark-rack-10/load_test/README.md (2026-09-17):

Es wurde ein Lasttest durchgeführt, um die Temperaturentwicklung des DGX Spark unter Volllast zu untersuchen. Der Test begann gegen 9:10 Uhr. Um etwa 9:18 Uhr wurde das Gerät in den Rackmount beziehungsweise das Gehäuse eingesetzt. Die Raumtemperatur lag während des Tests bei ungefähr 26 °C oder etwas darüber und war damit höher als üblich. Die Veränderung der Temperaturen vor und nach dem Einsetzen in das Gehäuse wurde anhand der aufgezeichneten Messwerte und Diagramme dokumentiert.
